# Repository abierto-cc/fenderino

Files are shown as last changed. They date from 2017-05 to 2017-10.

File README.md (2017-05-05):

# fenderino

Repositorio para el Fenderino Guitar Shield para Arduino UNO y equivalentes

Diseñado en Suecia con amor para toda la galaxia

# consigue tu kit

Si quieres conseguir el kit para montarlo, visita: https://abierto.cc/shop

# instrucciones de montaje

Puedes ver las instrucciones de montaje paso a paso en: https://sites.google.com/abierto.cc/fenderino

# créditos

Marc Sibila y Jordi Divins de @instroniks y a todos los chicos de su orquesta

Xose Pérez por su contribución con el código MIDI para Arduino UNO y Arduino Leonardo

# autores

D. Cuartielles at abierto.cc (prueba de concepto + código)

J. Garcia at abierto.cc (diseño en KiCAD)

L. Balboa at abierto.cc (gráficos)

# menciones

* Artículo de X. Pérez y explicación sobre el uso de la guitarra con MIDI: http://tinkerman.cat/fenderino-arducaster-the-coolest-guitar/

# licencia para hardware y documentation

<br /><span xmlns:dct="http://purl.org/dc/terms/" href="http://purl.org/dc/dcmitype/Dataset" property="dct:title" rel="dct:type">Fenderino Arducaster</span> by <a xmlns:cc="http://creativecommons.org/ns#" href="https://abierto.cc" property="cc:attributionName" rel="cc:attributionURL">Proyecto Abierto</a> is licensed under a <a rel="license" href="http://creativecommons.org/licenses/by-nc-sa/4.0/">Creative Commons Reconocimiento-NoComercial-CompartirIgual 4.0 Internacional License</a>.<br />Creado a partir de la obra en <a xmlns:dct="http://purl.org/dc/terms/" href="https://github.com/abierto-cc/fenderino" rel="dct:source">https://github.com/abierto-cc/fenderino</a>

# licencia para código de ejemplos

El código está liberado bajo licencia GPLv3, se recomienda leer el fichero de licencia para más información

# abierto

Abierto es una inciativa de D. Cuartielles gracias a la generosa aportación de la Fundación PUIG por intermediación de la Fundación Ashoka de cara a contribuir a la creación de material educativo de libre acceso y circulación

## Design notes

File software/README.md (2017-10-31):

# Fenderino Shield - código y libreras

Esta carpeta contiene los ejemplos de código que necesitas para poder empezar a experimentar con tu Fenderino. La subcarpeta *examples* tiene todo lo que necesitas para poder empezar a experimentar

En cualquier caso, para poder probar la carpeta *examples* habrá un momento en el que necesitarás librerías. Hemos incluido bajo *libraries* dos librerías que debieras instalar dentro de tu carpeta de _Sketchbook_ del IDE de Arduino. Es posible que ya tengas estas librerías, no hemos hecho ninguna modificación sobre ellas, sólo las compartimos para que sea más sencillo el encontrarlas

# librería Synth

Esta librería la creó DZL en Illutron (Copenague) en el año 2014 y la puedes econtrar en https://github.com/dzlonline/the_synth . Se trata de una librería que genera hasta 4 tonos diferentes usando los tipos de ondas: ruido, cuadradra, triangular, sinusoide. Estos cuatro tonos simultáneos se pueden asignar a un solo pin con lo que puedes crear tus propios instrumentos al crear el timbre del instrumento usando la suma de los tonos 

El código original de DZL no presenta una licencia de uso, por lo que nosotros le asignamos GPLv3 hasta que nos digan lo contrario

# librería Talkie

Esta librería la creó Peter Knight en el año 2011 y la puedes econtrar en https://github.com/going-digital/Talkie . Se trata de una librería de sńtesis de voz que puede reproducir sonidos almacenados como una tabla de ondas comprimida usando tablas de ruido y envolventes. Es una técnica desarrollada en el pasado entre otros por Texas Instruments para la creación de sistemas de voz con microcontroladores teniendo el sonido grabado en memoria de programa

La usamos para el ejemplo en el que Fenderino dirá los números en inglés al presionar los botones. Además, la carpeta de la librería incluye código de Freemat para comprimir otros ficheros de audio

Aquí un reto para quien se anime: crear un algoritmo en Java que sea capaz de tomar un fichero WAV y generar un array de audio comprimido en formato texto para poder incluir en los programas hechos ocn Arduino. Abierto se compromete a hacer una herramienta para el IDE de Arduino que use ese código para automáticamente añadir el sonido a tus programas

Esta librería está licenciada bajo GPLv2, por lo que la licencia GPLv3 usada para todo el documento resulta aplicable

# ejemplo FA_8 - Midi por USB

Este ejemplo es una contribución de Xosé Pérez y requiere instalar otra librería, el ejemplo contiene toda la información necesaria como comentario dentro del código. Échale un vistazo y sigue las explicaciones paso a paso

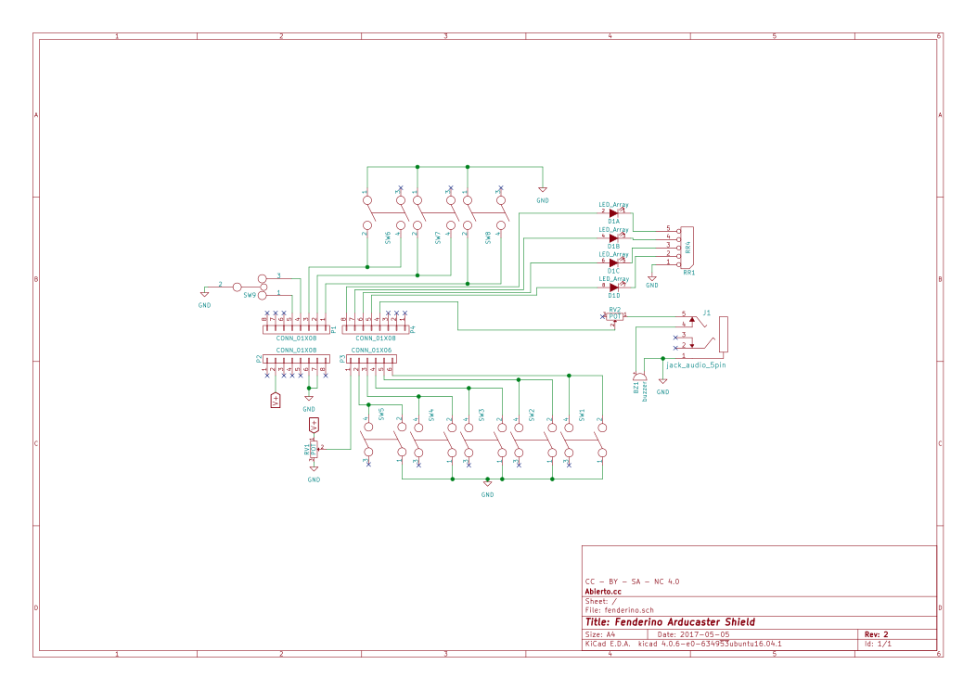
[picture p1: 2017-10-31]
hardware/pdf/Fenderino_AB0001R2_Schematic.png

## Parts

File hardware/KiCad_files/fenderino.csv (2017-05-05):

Reference | Value | Footprint | Datasheet
RV1 | POT | Switch:Potenciometro
RV2 | POT | Switch:Potenciometro
P3 | CONN_01X06 | Pin_Headers:Pin_Header_Straight_1x06
P2 | CONN_01X08 | Pin_Headers:Pin_Header_Straight_1x08
SW1 | Switch_DPST | Buttons_Switches_ThroughHole:SW_PUSH-12mm
SW2 | Switch_DPST | Buttons_Switches_ThroughHole:SW_PUSH-12mm
SW3 | Switch_DPST | Buttons_Switches_ThroughHole:SW_PUSH-12mm
SW4 | Switch_DPST | Buttons_Switches_ThroughHole:SW_PUSH-12mm
P1 | CONN_01X08 | Pin_Headers:Pin_Header_Straight_1x08
SW5 | Switch_DPST | Buttons_Switches_ThroughHole:SW_PUSH-12mm
SW6 | Switch_DPST | Buttons_Switches_ThroughHole:SW_PUSH-12mm
SW7 | Switch_DPST | Buttons_Switches_ThroughHole:SW_PUSH-12mm
SW8 | Switch_DPST | Buttons_Switches_ThroughHole:SW_PUSH-12mm
BZ1 | buzzer | Buzzers_Beepers:MagneticBuzzer_Kingstate_KCG0601
J1 | jack_audio_5pin | jack_audio:jack_audio_huella
D1 | LED_Array | array_LEDs:Array_4_LED
RR1 | RR4 | pth_resistors:r-sil_5
SW9 | SWITCH_INV_MSM | switch:switch_100sp5
P4 | CONN_01X08 | Pin_Headers:Pin_Header_Straight_1x08

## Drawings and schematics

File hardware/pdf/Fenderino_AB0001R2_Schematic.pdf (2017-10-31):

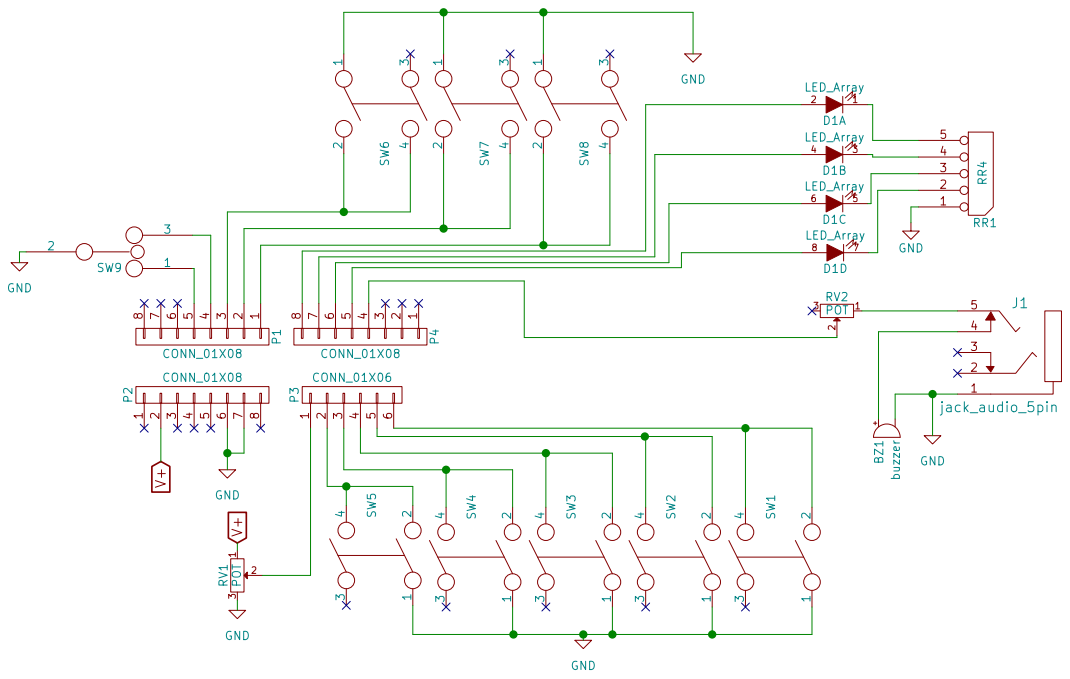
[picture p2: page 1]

File: fenderino.sch Sheet: / Abierto.cc CC - BY - SA - NC 4.0

Id: 1/1 Title: Fenderino Arducaster Shield

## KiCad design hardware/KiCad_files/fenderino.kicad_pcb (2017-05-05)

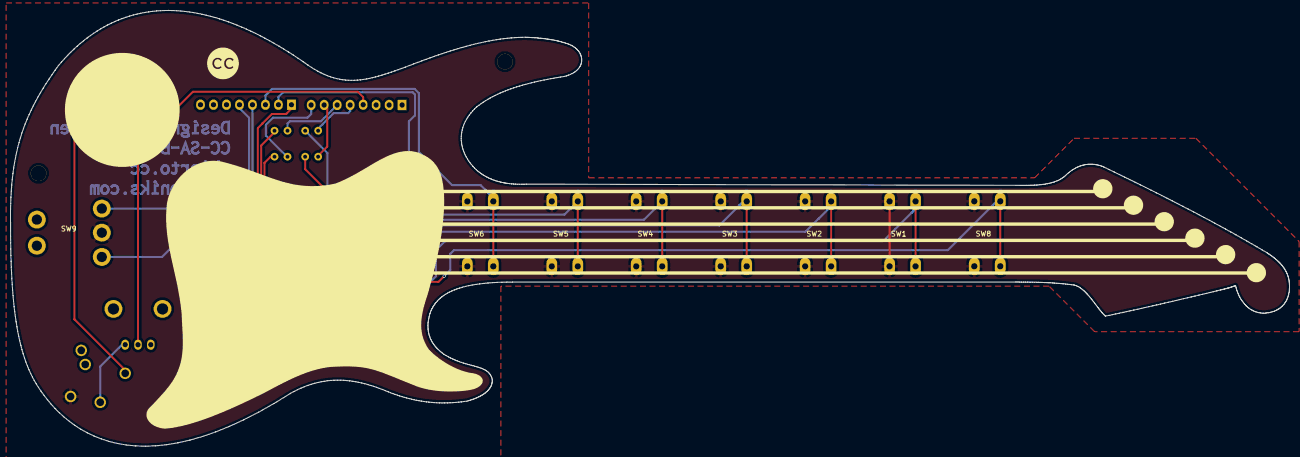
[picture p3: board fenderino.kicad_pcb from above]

Board: 2 copper layers, 250.1 x 85.2 mm, 21 parts (0 on the bottom side), 24 nets.

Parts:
BZ1: buzzer; buzzer_tmb
D1: LED_Array; Array_4_LED
J1: jack_audio_5pin; jack_huella
P1, P2, P4: CONN_01X08; Pin_Header_Straight_1x08
P3: CONN_01X06; Pin_Header_Straight_1x06
RR1: RR4; r-sil_5
RV1, RV2: POT; trimmer_alps-rk09k1130ah1
SW1, SW2, SW3, SW4, SW5, SW6, SW7, SW8: Switch_DPST; SW_PUSH-12mm
SW9: SWITCH_INV_MSM; switch
svg2mod: G***; svg2mod
svg2mod-rev: G***; svg2mod-rev

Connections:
GND: BZ1.2, J1.1, P2.6, P2.7, RR1.1, RV1.3, SW1.1, SW2.1, SW3.1, SW4.1, SW5.1, SW6.1, SW7.1, SW8.1, SW9.2
unnamed: BZ1.1, J1.4
unnamed: D1.1, RR1.5
unnamed: D1.2, P4.8
unnamed: D1.3, RR1.4
unnamed: D1.4, P4.7
unnamed: D1.5, RR1.3
unnamed: D1.6, P4.6
unnamed: D1.7, RR1.2
unnamed: D1.8, P4.5
unnamed: J1.5, RV2.1
unnamed: P1.1, SW8.2
unnamed: P1.2, SW7.2
unnamed: P1.3, SW6.2
unnamed: P1.4, SW9.3
unnamed: P1.5, SW9.1
unnamed: P3.1, RV1.2
unnamed: P3.2, SW5.2
unnamed: P3.3, SW4.2
unnamed: P3.4, SW3.2
unnamed: P3.5, SW2.2
unnamed: P3.6, SW1.2
unnamed: P4.4, RV2.2
V+: P2.2, RV1.1

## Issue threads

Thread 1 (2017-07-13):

¿BOM disponible?

sabas1080, 2017-07-13:
Hola

¿Hay un lugar donde pueda encontrar el BOM con numero de parte de los coponentes necesarios para armar mi propio Fenderino?

Muchas gracias, excelente proyecto, saludos desde México

MrHofflich, 2017-07-13:
Si por favor, lo he estado buscando de hace tiempo ya pero al parecer no está.

Gracias y saludos desde México!

dcuartielles, 2017-07-15:
Hola chicos, perdón que no haya respondido antes a esta notificación. Tengo apagadas las notificaciones de github porque estoy metido en tantos repositorios que mi cuenta de mail es imposible de manejar. Así que tengo que ir mirando uno por uno.

En cualquier caso, el BOM no está colgado por error, se puede extraer directamente de las instrucciones de montaje, pero en cualquier caso en cuanto José -que mantiene el diseño- regrese de vacaciones en la semana que entra, le pediré que lo cuelgue. Es más, le voy asignar este issue ;-)

¡Estad atentos!

GDJose, 2017-07-19:
Hola,
Ya está disponible el BOM

sabas1080, 2017-07-19:
Muchas gracias @GDJose

Closed 2017-07-19.

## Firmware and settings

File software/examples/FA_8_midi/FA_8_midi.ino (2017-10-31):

/*
    The Fenderino Arducaster Series

    Capítulo 8: Escala Con Botones, Potenciómetro y salida MIDI polifónica

    Toca una escala usando los botones de la guitarra, el potenciómetro
    te permite subir y bajar la escala, cuando la escala se ajuste a
    la primera tecla (es decir, Do en la primera tecla amarilla) las luces
    parpadean todas juntas

    Con el interruptor hacia arriba la salida es MIDI, el comportamiento es
    exactamente el mismo que el descrito en el párrafo anterior pero además
    tienes sonido polifónico (puedes tocar más de una tecla a la vez).

    ARDUINO LEONARDO (fácil) ---------------------------------------------------

    Este sketch utiliza la libreria "MIDIUSB" de Gary Grewal & Arduino
    (disponible desde el gestor de librerías del IDE de Arduino) para gestionar
    las notas desde el Leonardo:

    ==> https://github.com/arduino-libraries/MIDIUSB

    ARDUINO UNO (un poco más difícil) ------------------------------------------

    Este sketch utiliza la libreria "MIDI Library" de FortySevenEffects
    (disponible desde el gestor de librerías del IDE de Arduino) para gestionar
    las notas desde el Uno:

    ==> https://github.com/FortySevenEffects/arduino_midi_library

    Para que la connexión MIDI funcione via USB el controlador serie de la
    placa (atmega8u2 o atmega16u2) debe flashearse con el firmware HIDUINO:

    ==> https://github.com/ddiakopoulos/hiduino

    Para modificar el firmware del atmega16u2 y después para programar el
    atmega328p necesitarás un programador AVR. Para subir el código al
    atmega328 sitúa el interruptor en el centro.

    ----------------------------------------------------------------------------

    Una vez subido el código conecta tu Arduino (Uno o Leonardo) por USB a un
    cliente MIDI y selecciona la entrada "arduino_midi:0" (Uno) o
    "Arduino Leonardo:0" (Leonardo) y a tocar!

    Este codigo esta licenciado bajo GPLv3

    (c) 2017 D. Cuartielles para Abierto.cc
    (c) 2017 Xose Pérez (MIDI y soporte para Leonado)

*/

// -----------------------------------------------------------------------------

#include "Arduino.h"

// incluye los nombres de las notas
#include "pitches.h"
#include "pitches_midi.h"

#ifdef ARDUINO_AVR_UNO
    #include <MIDI.h>
    MIDI_CREATE_DEFAULT_INSTANCE();
#endif
#ifdef ARDUINO_AVR_LEONARDO
    #include "MIDIUSB.h"
#endif

// -----------------------------------------------------------------------------

// configuración del MIDI (comentar primera línea para desactivar MIDI)
#define MIDI_CHANNEL    1
#define MIDI_VELOCITY   64

// define los pines
int speaker = 3;
int botones[] = {9, 10, A1, A2, A3, A4, A5, 8};
int interruptor[] = {11, 12};
int leds[] = {4, 5, 7, 6};

// define arrays donde almacenar los valores
int valBotones[8] = {};
int valNotas[8] = {0};
int valInterruptor[2] = {};
int valLeds[4] = {};
int valPot = 0;
int valCount = 0; // contador para almacenar que led se enciende

// variable para definir los tiempos de ciclo
long timer = 0;

// variables para definir cuando se mandan datos por el puerto serie
long timerSerie = 0;
long timerSerieValor = 500;

// variables para contorlar los avisos visuales
boolean aviso = true;
int avisoCount = 0;
long timerAvisoValor = 200;

// define las frecuencias de las notas para cada boton
int frecuencia[] = {
    NOTE_C1, NOTE_D1, NOTE_E1, NOTE_F1, NOTE_G1, NOTE_A1, NOTE_B1,
    NOTE_C2, NOTE_D2, NOTE_E2, NOTE_F2, NOTE_G2, NOTE_A2, NOTE_B2,
    NOTE_C3, NOTE_D3, NOTE_E3, NOTE_F3, NOTE_G3, NOTE_A3, NOTE_B3,
    NOTE_C4, NOTE_D4, NOTE_E4, NOTE_F4, NOTE_G4, NOTE_A4, NOTE_B4,
    NOTE_C5, NOTE_D5, NOTE_E5, NOTE_F5, NOTE_G5, NOTE_A5, NOTE_B5,
    NOTE_C6, NOTE_D6, NOTE_E6, NOTE_F6, NOTE_G6, NOTE_A6, NOTE_B6,
    NOTE_C7, NOTE_D7, NOTE_E7, NOTE_F7, NOTE_G7, NOTE_A7, NOTE_B7,
    NOTE_C8, NOTE_D8,
};

// números de las notas MIDI
int notes[] = {
    MIDI_NOTE_C1, MIDI_NOTE_D1, MIDI_NOTE_E1, MIDI_NOTE_F1, MIDI_NOTE_G1, MIDI_NOTE_A1, MIDI_NOTE_B1,
    MIDI_NOTE_C2, MIDI_NOTE_D2, MIDI_NOTE_E2, MIDI_NOTE_F2, MIDI_NOTE_G2, MIDI_NOTE_A2, MIDI_NOTE_B2,
    MIDI_NOTE_C3, MIDI_NOTE_D3, MIDI_NOTE_E3, MIDI_NOTE_F3, MIDI_NOTE_G3, MIDI_NOTE_A3, MIDI_NOTE_B3,
    MIDI_NOTE_C4, MIDI_NOTE_D4, MIDI_NOTE_E4, MIDI_NOTE_F4, MIDI_NOTE_G4, MIDI_NOTE_A4, MIDI_NOTE_B4,
    MIDI_NOTE_C5, MIDI_NOTE_D5, MIDI_NOTE_E5, MIDI_NOTE_F5, MIDI_NOTE_G5, MIDI_NOTE_A5, MIDI_NOTE_B5,
    MIDI_NOTE_C6, MIDI_NOTE_D6, MIDI_NOTE_E6, MIDI_NOTE_F6, MIDI_NOTE_G6, MIDI_NOTE_A6, MIDI_NOTE_B6,
    MIDI_NOTE_C7, MIDI_NOTE_D7, MIDI_NOTE_E7, MIDI_NOTE_F7, MIDI_NOTE_G7, MIDI_NOTE_A7, MIDI_NOTE_B7,
    MIDI_NOTE_C8, MIDI_NOTE_D8,
};

// nota midi que está sonando
unsigned int anterior = 0;

// define donde se empiezan a contar los tonos del array de frecuencias
int indice = 0;
int indiceOld = 1; // ese lo usaremos para saber cuando cambia

// -----------------------------------------------------------------------------

void midiControl(byte control, byte value, byte channel) {
    #ifdef ARDUINO_AVR_UNO
        MIDI.sendControlChange(control, value, channel);
    #endif
    #ifdef ARDUINO_AVR_LEONARDO
        midiEventPacket_t event = {0x0B, 0xB0 | channel, control, value};
        MidiUSB.sendMIDI(event);
    #endif
}

void midiNoteOn(byte pitch, byte velocity, byte channel) {
    #ifdef ARDUINO_AVR_UNO
        MIDI.sendNoteOn(pitch, velocity, channel);
    #endif
    #ifdef ARDUINO_AVR_LEONARDO
        midiEventPacket_t noteOn = {0x09, 0x90 | channel, pitch, velocity};
        MidiUSB.sendMIDI(noteOn);
    #endif
}

void midiNoteOff(byte pitch, byte velocity, byte channel) {
    #ifdef ARDUINO_AVR_UNO
        MIDI.sendNoteOff(pitch, velocity, channel);
    #endif
    #ifdef ARDUINO_AVR_LEONARDO
        midiEventPacket_t noteOff = {0x08, 0x80 | channel, pitch, velocity};
        MidiUSB.sendMIDI(noteOff);
    #endif
}

// -----------------------------------------------------------------------------

void setup() {

    // inicializa todos los botones como pines en pull-up
    for (int i = 0; i < 8; i++) pinMode(botones[i], INPUT_PULLUP);

    // inicializa el interruptor como pull-up
    for (int i = 0; i < 2; i++) pinMode(interruptor[i], INPUT_PULLUP);

    // inicializa el led como salida
    for (int i = 0; i < 4; i++) pinMode(leds[i], OUTPUT);

    // inicializa la salida de audio
    pinMode(speaker, OUTPUT);

    // inicializa el temporizador
    timer = millis();

    // inicializa el interfaz MIDI para el uno
    #ifdef ARDUINO_AVR_UNO
        MIDI.begin();
    #endif
    midiControl(0, 0, 1);

}

void loop() {


    // lee toda la informacion y almacenala en sus arrays y variables correspondientes
    for (int i = 0; i < 8; i++) {
        valBotones[i] = digitalRead(botones[i]);
    }
    for (int i = 0; i < 2; i++) {
        valInterruptor[i] = digitalRead(interruptor[i]);
    }
    valPot = analogRead(A0);

    // calculamos el desplazamiento de la nota en función del potenciómetro
    indice = round( map(valPot, 0, 1023, 0, (sizeof(frecuencia) / sizeof(int)) - 7) );

    // si el indice es multiplo de 8, que es el principio de escala, haz un aviso visual
    if (indice % 8 == 0 && indiceOld != 0) {
        aviso = true;
    }

    // con el interruptor hacia arriba hacemos sonar una nota por el speaker de la guitarra
    if (valInterruptor[0] == 0) {

        // asigna la nota dando preferencia a la mas alta si se aprietan dos teclas
        int nota = -1;
        for (int i = 0; i < 8; i++) {
            if (valBotones[i] == 0)
            nota = i;
        }

        if (nota > -1) {
            tone(3, frecuencia[nota + indice]);
        } else {
            noTone(3);
        }

    // con el interruptor hacia abajo hacemos sonar una nota por el interfaz MIDI
    } else if (valInterruptor[1] == 0) {

        for (int i = 0; i < 8; i++) {

            // calculamos el codigo de nota si el botón está pulsado o 0 si no
            int nota = (valBotones[i] == 0) ? notes[i+indice] : 0;

            // si la nota para esta posición ha cambiado deberemos cambiar la salida MIDI
            if (nota != valNotas[i]) {

                // si estaba sonando una nota la apagamos
                if (valNotas[i] > 0) {
                    midiNoteOff(valNotas[i], MIDI_VELOCITY, MIDI_CHANNEL);
                }

                // hacemos sonar la nota nueva (si se está pulsando el botón)
                if (nota > 0) {
                    midiNoteOn(nota, MIDI_VELOCITY, MIDI_CHANNEL);
                }

                // y guardamos registro de qué nota está sonando en esta posición
                valNotas[i] = nota;

            }

        }

    } else {

        noTone(3);

        // apagamos las notas que puedan estar sonando
        for (int i = 0; i < 8; i++) {
            if (valNotas[i] > 0) {
                midiNoteOff(valNotas[i], MIDI_VELOCITY, MIDI_CHANNEL);
                valNotas[i] = 0;
            }
        }

    }

    #ifdef ARDUINO_AVR_LEONARDO
        MidiUSB.flush();
    #endif

    // mapea el paso del tiempo en los leds, controlalo con el potenciometro
    // pero solo cuando no estes ejecutando una secuencia de aviso
    if (millis() - timer > valPot && !aviso) {

        valCount++;
        valCount %= 4;

        // enciende el led
        for (int i = 0; i < 4; i++) {
            if (i == valCount) digitalWrite(leds[i], HIGH);
            else digitalWrite(leds[i], LOW);
        }

        timer = millis();

    }

    // ejecuta una secuencia de aviso en los leds
    if (millis() - timer > timerAvisoValor && aviso) {

        avisoCount++;
        if (avisoCount % 2 == 0) {
            // enciende los leds
            for (int i = 0; i < 4; i++) {
                digitalWrite(leds[i], HIGH);
            }
        } else {
            // apaga los leds
            for (int i = 0; i < 4; i++) {
                digitalWrite(leds[i], LOW);
            }
        }

        // decide no volver a entrar is se llego al maximo
        if (avisoCount > 6) {
            avisoCount = 0;
            aviso = false;
        }

        timer = millis();

    }

    // guarda informacion de los indices
    indiceOld = indice;

}

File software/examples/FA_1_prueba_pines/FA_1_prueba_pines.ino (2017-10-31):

/*
 * The Fenderino Arducaster Series
 * 
 * Capitulo 1: Manejo de los pines de entrada salida
 * 
 * El shield Fenderino Arduicaster hace uso de practicamente todos pines
 * de entrada / salida de tu Arduino Uno. La razon es que tenemos:
 * 
 * - 8 pulsadores para tocar notas
 * - un potenciometro controlable por software
 * - una salida de audio
 * - un cubo de 4 leds para efectos visuales
 * - un interruptor de 3 posiciones
 * - ademas contamos con un potenciometro para controlar el volumen de salida
 * 
 * Este sketch se encarga de mapear todos los valores de los botones, interruptor, potenciometro
 * hacia los cuatro leds de salida y el puerto serie, de modo que puedas aprender algo mas
 * sobre como funciona el Shield y la placa Arduino
 * 
 * Este codigo esta licenciado bajo GPLv3
 * 
 * (c) 2017 D. Cuartielles para Abierto.cc
 * 
 */

// define los pines
int speaker = 3;
int botones[] = {9, 10, 15, 16, 17, 18, 19, 8};
int interruptor[] = {11, 12};
int leds[] = {4, 5, 7, 6};

// define arrays donde almacenar los valores
int valBotones[8] = {};
int valInterruptor[2] = {};
int valLeds[4] = {};
int valPot = 0;

void setup() {
  // incializa el puerto serie
  Serial.begin(115200);

  // inicializa todos los botones como pines en pull-up
  for (int i = 0; i < 8; i++) pinMode(botones[i], INPUT_PULLUP);

  // inicializa el interruptor como pull-up
  for (int i = 0; i < 2; i++) pinMode(interruptor[i], INPUT_PULLUP);

  // inicializa el led como salida
  for (int i = 0; i < 4; i++) pinMode(leds[i], OUTPUT);

  // inicializa la salida de audio
  pinMode(speaker, OUTPUT);

}

void loop() {
  // lee toda la informacion y almacenala en sus arrays y variables correspondientes
  for (int i = 0; i < 8; i++) {
    valBotones[i] = digitalRead(botones[i]);
  }
  for (int i = 0; i < 2; i++) {
    valInterruptor[i] = digitalRead(interruptor[i]);
  }
  valPot = analogRead(A0);

  // mapea el potenciometro en los leds
  int numLed = int(map(valPot, 0, 1023, 0, 4));
  for (int i = 0; i < 4; i++) {
    if (i == numLed) digitalWrite(leds[i], HIGH);
    else digitalWrite(leds[i], LOW);
  }

  // envia los valores por el puerto serie
  for (int i = 0; i < 8; i++) {
    Serial.print(valBotones[i]); Serial.print(" | ");
  }
  for (int i = 0; i < 2; i++) {
    Serial.print(valInterruptor[i]); Serial.print(" | ");
  }
  Serial.println(valPot);

  delay(100);

}

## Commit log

2017-05-05 Archivos de KiCad y Gerber del Fenderino Guitar Shield
    [fenderino.csv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]
2017-07-19 BOM del Fendrino
